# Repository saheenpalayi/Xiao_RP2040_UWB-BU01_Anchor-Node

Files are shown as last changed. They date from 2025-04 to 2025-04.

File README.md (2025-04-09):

# Xiao RP2040 UWB-BU01 Anchor-Node!

 The UWB (Ultra wide band ) is a cool thing to have in projects involve indoor location tracking and robotics, tracking devices, Then there is a Module called BU01 DW1000 available for the maker's to explore and add this amazing pice of technology to their project, This documentation of mine is a step to the UWB and the Xiao that I did in Super Fablab Kerala - Koch  

Here is the cool board I made with the Module and Xiao ESP32 C6

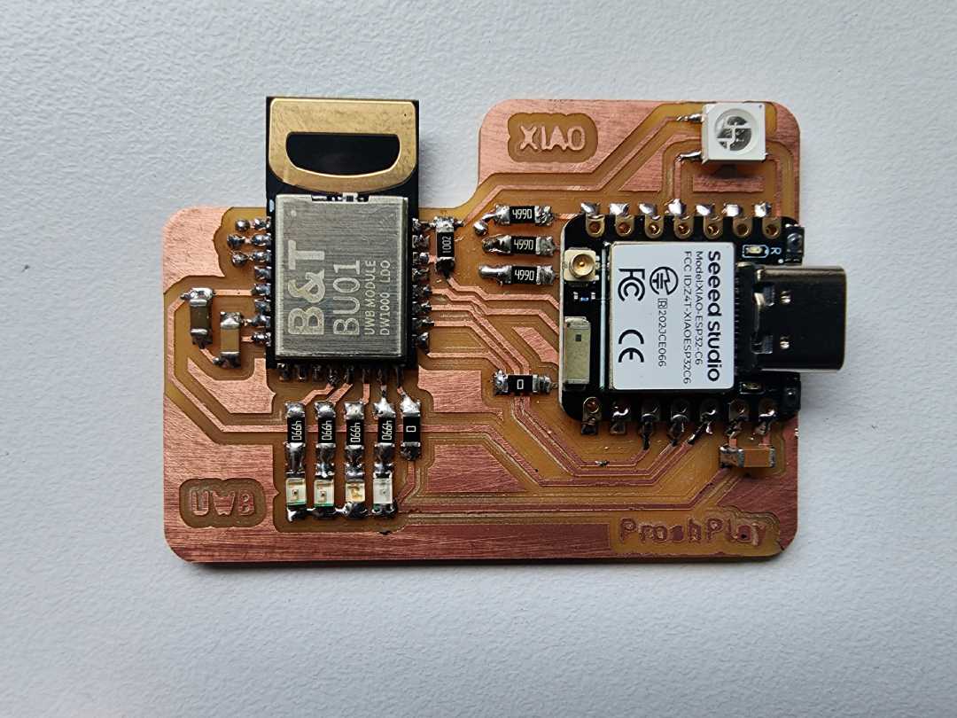
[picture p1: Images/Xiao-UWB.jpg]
Xiao_UWB


## Design of the Board 
I've used Kicad to design the PCB and the Design files and gerber files are included in the repo. I've been following the Makerbase documentation to see the available commercial development board's schematics for the reference and the datasheet of the module all linked bottom of the board. The foot print I've got one of my student Akash at the Fabacademy 2025 who was exploring the Module for his fabacademy final project 
### Schematic
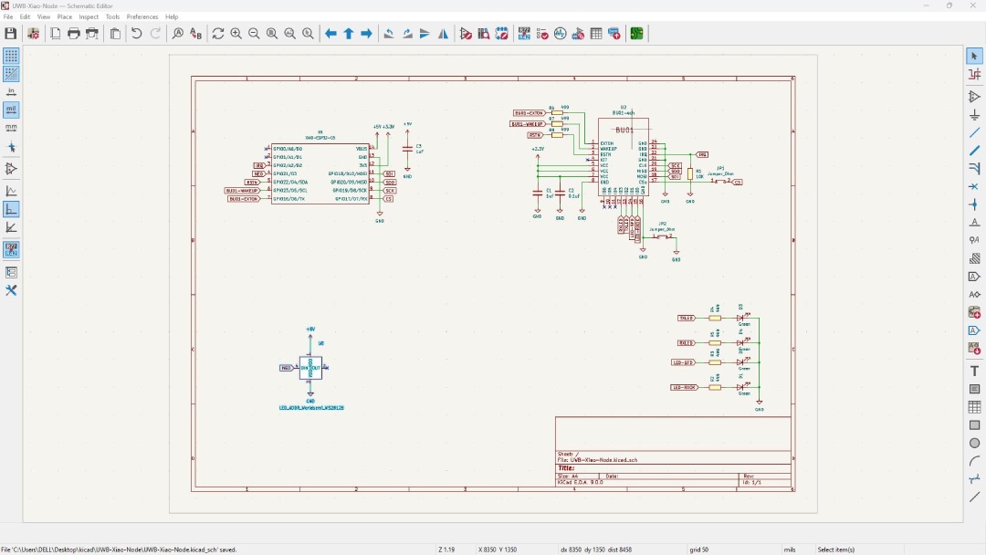
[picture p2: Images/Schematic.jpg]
Schematic


### PCB Layout
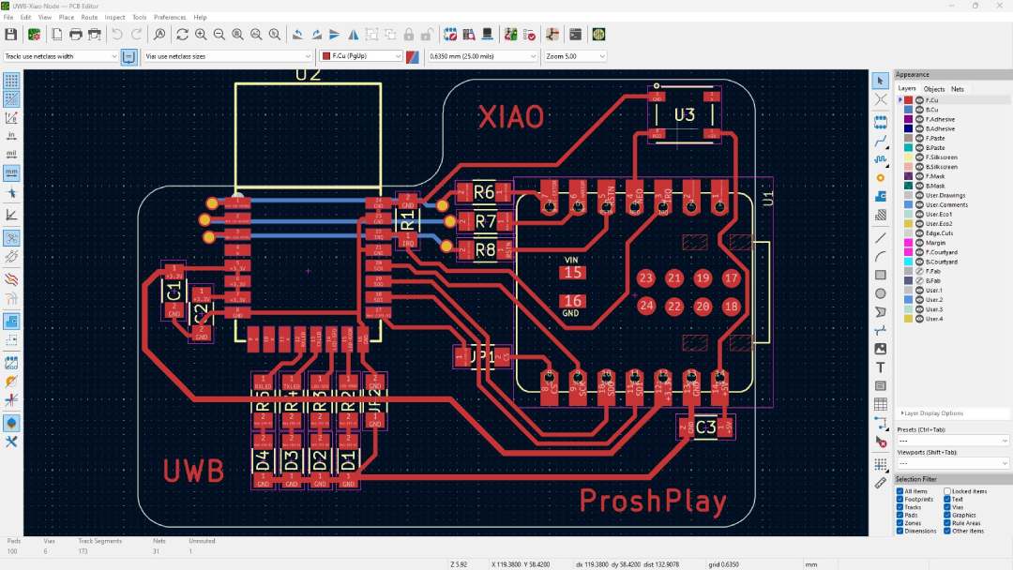
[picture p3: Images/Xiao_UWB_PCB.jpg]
PCB


### PCB 3D view
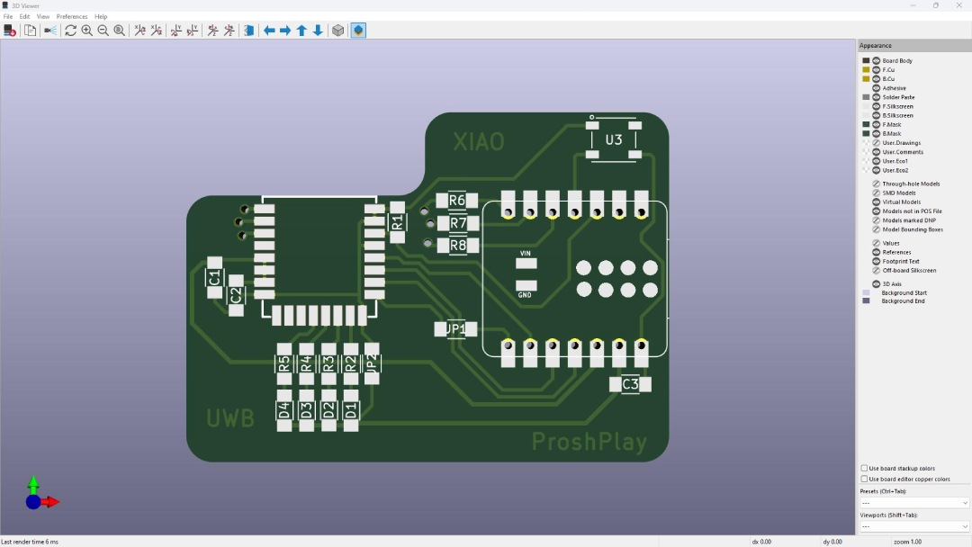
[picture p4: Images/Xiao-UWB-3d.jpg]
3D-PCB


## Issues 
 I've faced several issues with the experiment with the new Xiao ESP32 C6 and the module probably the library support I assume

 - The libraries not compiling initially coz its made for older version of Espressif Board
 - the BU01's IRQ pin connected to the Xiao Esp32 C6 is giving an exceptional error on the serial monitor 

 ## Fixes

- Replaced the Xiao ESP32 C6 with the Xiao RP2040 (it was easy since both share same pin footprints)

## References

- [Makerfabs Wiki](https://wiki.makerfabs.com/ESP32_UWB.html) 
- [BU01 Datasheet](https://docs.ai-thinker.com/_media/uwb/docs/bu01_product_specification_en_v1.0.pdf)
- [Getting Started with ESP32 DW1000 UWB (Ultra Wideband) Module](https://how2electronics.com/getting-started-with-esp32-dw1000-uwb-ultra-wideband-module/)
- [Arduino DW1000 Library](https://github.com/thotro/arduino-dw1000/tree/master)

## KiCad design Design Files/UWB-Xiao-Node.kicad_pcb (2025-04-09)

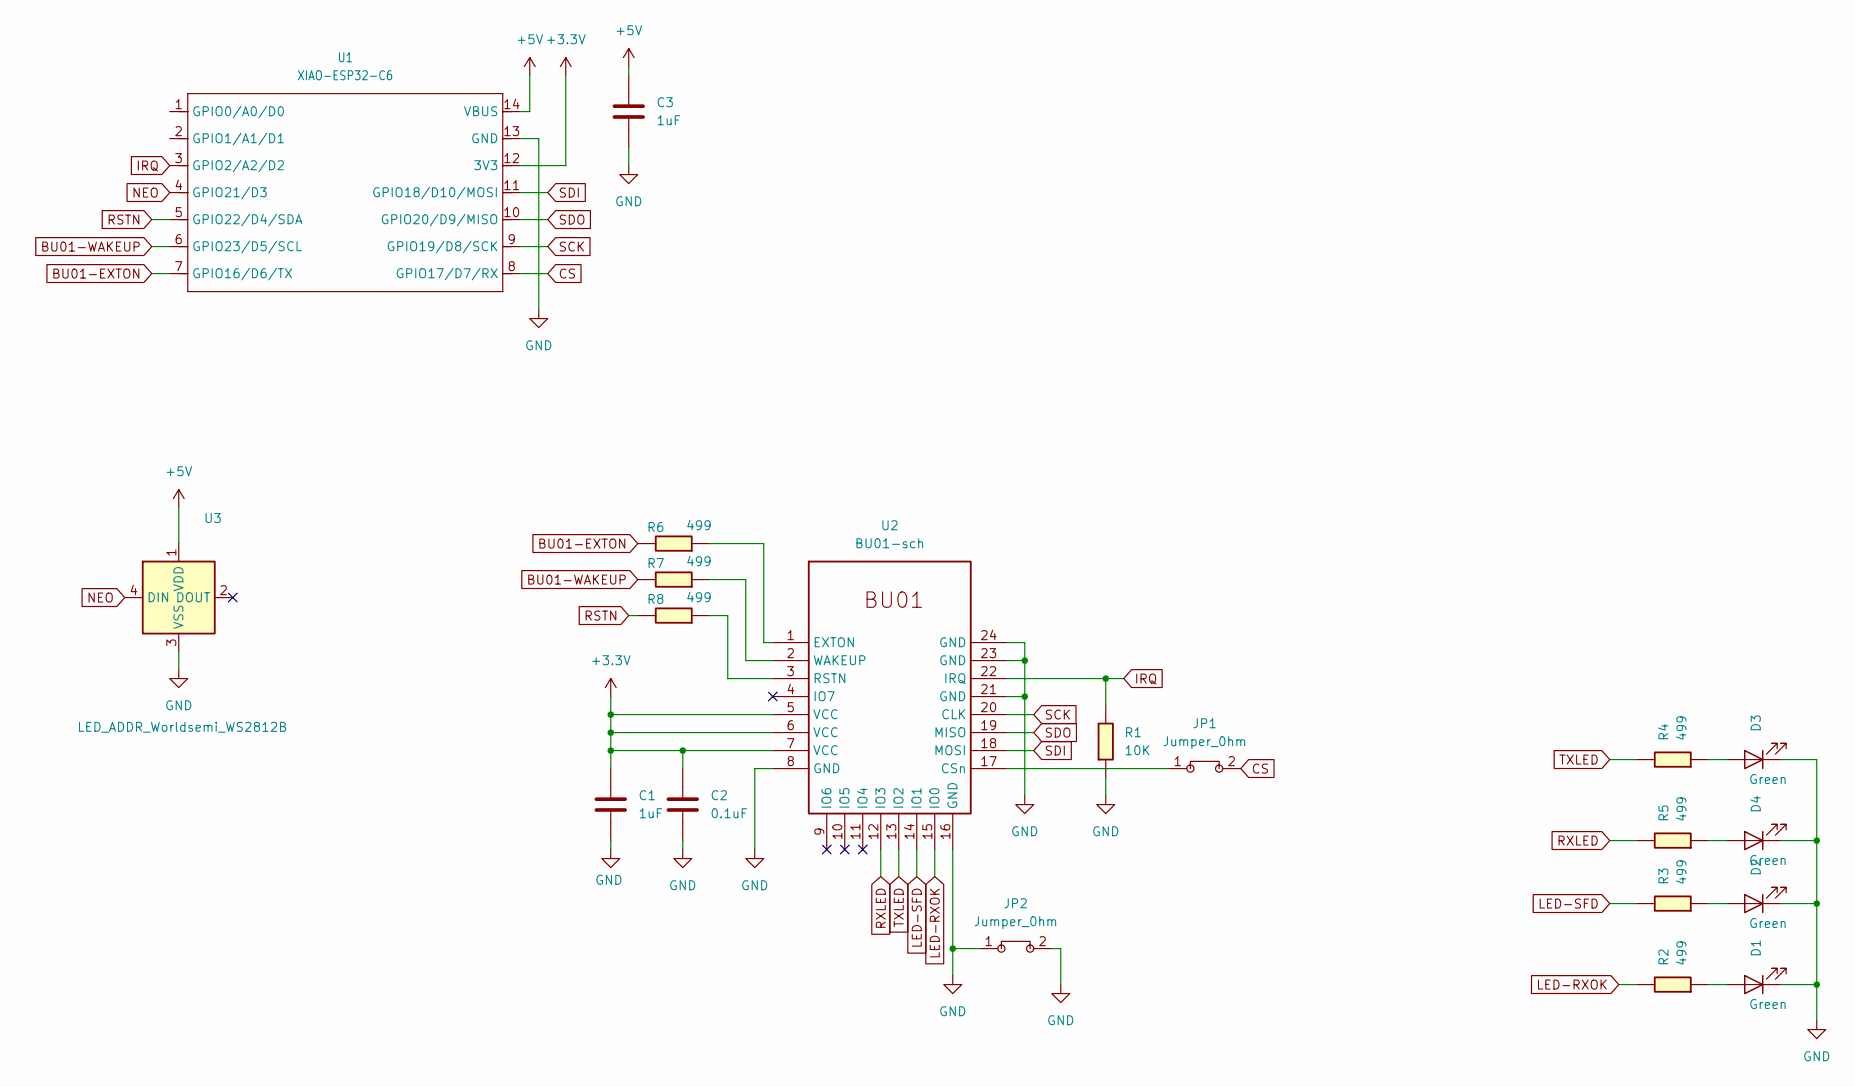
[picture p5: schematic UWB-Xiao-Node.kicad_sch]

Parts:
C1, C3: 1uF; C_1206
C2: 0.1uF; C_1206
D1, D2, D3, D4: Green; LED_1206
JP1, JP2: Jumper_0hm; Jumper_1206
R1: 10K; R_1206
R2, R3, R4, R5, R6, R7, R8: 499; R_1206
U1: XIAO-ESP32-C6; XIAO-ESP32C6-SMD
U2: BU01-sch; BU01
U3: LED_ADDR_Worldsemi_WS2812B

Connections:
+3.3V: C1.1, C2.1, U1.12 (3V3), U2.5 (VCC), U2.6 (VCC), U2.7 (VCC)
+5V: C3.1, U1.14 (VBUS), U3.1 (VDD)
BU01-EXTON: R6.1, U1.7 (GPIO16/D6/TX)
BU01-WAKEUP: R7.1, U1.6 (GPIO23/D5/SCL)
CS: JP1.2 (B), U1.8 (GPIO17/D7/RX)
GND: C1.2, C2.2, C3.2, D1.1 (K), D2.1 (K), D3.1 (K), D4.1 (K), JP2.1 (A), JP2.2 (B), R1.2, U1.13 (GND), U2.8 (GND), U2.16 (GND), U2.21 (GND), U2.23 (GND), U2.24 (GND), U3.3 (VSS)
IRQ: R1.1, U1.3 (GPIO2/A2/D2), U2.22 (IRQ)
LED-RXOK: R2.1, U2.15 (IO0)
LED-SFD: R3.1, U2.14 (IO1)
NEO: U1.4 (GPIO21/D3), U3.4 (DIN)
unnamed: D1.2 (A), R2.2
unnamed: D2.2 (A), R3.2
unnamed: D3.2 (A), R4.2
unnamed: D4.2 (A), R5.2
unnamed: JP1.1 (A), U2.17 (CSn)
unnamed: R6.2, U2.1 (EXTON)
unnamed: R8.2, U2.3 (RSTN)
unnamed: R7.2, U2.2 (WAKEUP)
RSTN: R8.1, U1.5 (GPIO22/D4/SDA)
RXLED: R5.1, U2.12 (IO3)
SCK: U1.9 (GPIO19/D8/SCK), U2.20 (CLK)
SDI: U1.11 (GPIO18/D10/MOSI), U2.18 (MOSI)
SDO: U1.10 (GPIO20/D9/MISO), U2.19 (MISO)
TXLED: R4.1, U2.13 (IO2)

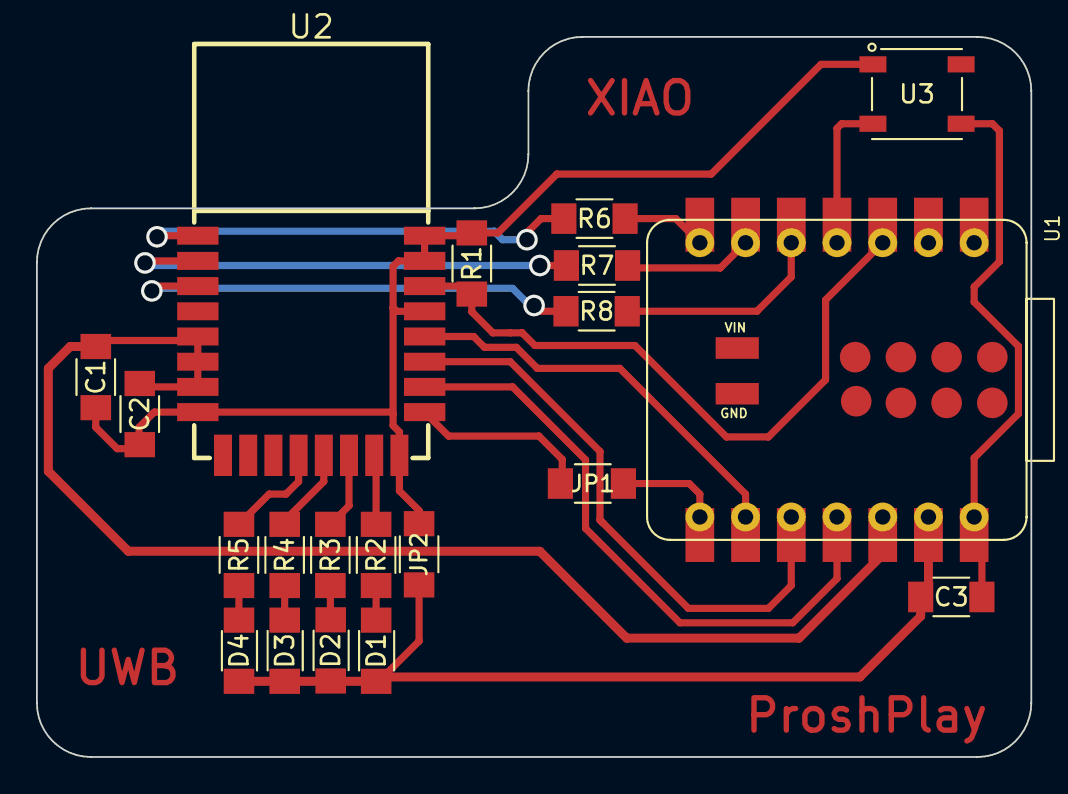
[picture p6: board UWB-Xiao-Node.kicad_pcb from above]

Board: 2 copper layers, 55.2 x 40.0 mm, 20 parts (0 on the bottom side), 24 nets.
